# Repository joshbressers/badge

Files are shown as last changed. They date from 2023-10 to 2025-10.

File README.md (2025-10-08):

This code is no longer maintained, everything got too complicated. You should go to the new home of this project
https://github.com/OpenBadgeProject

# Open Badge Project



This is the Open Badge Project. The idea behind this is to have a very low cost, low power electronic badge. These could be built just for fun, or if you're throwing a conference, feel free to use the PCB as the badge, maybe build some, maybe let the folks at the conference build them.

Electronic badges have gotten pretty hip, but they seem to suffer from two primary problems.
1) They are very expensive
1) They need a lot of batteries

The goal of the Open Badge Project was to build a badge that costs $5 or less and can run for a day or more on one 2032 battery.

The badge as it stands right now will only cost $5 if you build A LOT (1000 or more). The cost is closer to $6 or $7 for smaller batches at the moment, but that's still pretty reasonable.

### Types
There are two versions of the badge. One is a through hole badge that's very easy to solder. It was designed with human fabricators in mind. The kicad files in the main branch are for the through hole model.

There is also a surface mount version in the [surface-mount](https://github.com/joshbressers/badge/tree/surface-mount) branch. This version of the badge can be sent off to a fabricator to be mass produced.

Both badge versions use the same code.

## How does it work?
The badge itself runs on a microprocessor called an ATTINY85. It has 8K of program space, 512 bytes (yes, bytes) of memory. That microprocessor then drives 3 shift registers. One for the button input, and two for the display output. Shift registers shouldn't be used to drive LEDs, but it works, and doing it this way keeps the cost down.

The PCB can be shipped off to one of the countless PCB manufacturers that exist. There is room on the front for a logo. There is also plenty of room on the back for graphics. Instructions for swapping in your own logo can be found below.

The PCB was designed using KiCad, version 7.0 to be precise. Your mileage may very if you try to use other versions.

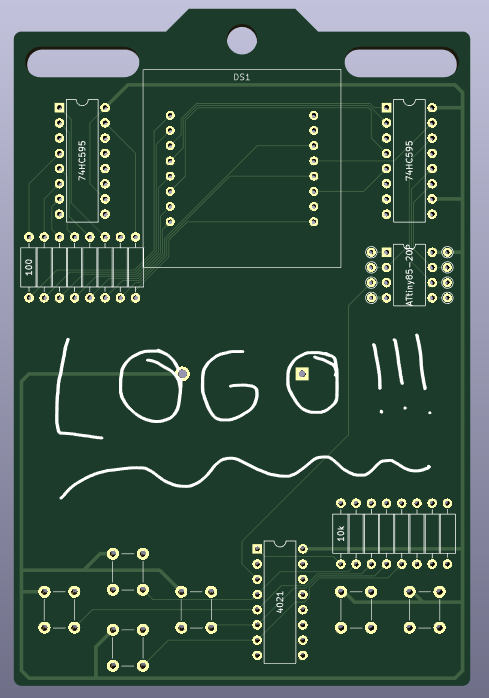
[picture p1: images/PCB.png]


## Parts List
You can generate a bill of materials from KiCad, but for the sake of simplicity here is a list of all the parts.

- 1 [ATTINY85](https://www.digikey.com/en/products/detail/microchip-technology/ATTINY85-20PU/735469)
- 1 PCB (you have to get this made, you can't buy them)
- 2 [CD74HC595E](https://www.digikey.com/en/products/detail/texas-instruments/CD74HC595E/1507396) shift registers
- 1 [CD4021BE](https://www.digikey.com/en/products/detail/texas-instruments/CD4021BE/67261) shift register
- 1 [2032 battery holder](https://www.digikey.com/en/products/detail/adam-tech/BH-25C-1/13537703)
- 8 [100 Ohm resistors](https://www.digikey.com/en/products/detail/stackpole-electronics-inc/CF14JT100R/1741261)
- 8 [100K Ohm resistors](https://www.digikey.com/en/products/detail/stackpole-electronics-inc/CF14JT10K0/1741265)
- 6 [Buttons](https://www.amazon.com/gp/product/B07VSNN9S2/ref=ppx_yo_dt_b_asin_title_o00_s00?ie=UTF8&th=1)
- 1 [8x8 LED Display](https://www.aliexpress.us/item/3256805713726832.html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)

There may be better places to purchase these things than these links. Please submit a PR if you find something better.

## How to change the logo
KiCad has a tool called "Image Converter". This application lets you turn an image into a footprint that can be added to the PCB layout.

When you run the tool, there is a button on the left called "Load Source Image". If you have a black and white image to start with that's the best. You can use any image but things get weird.

Once you load an image you will need to watch the size. The "Output Size" field is what matters here. It will take a few tries to get it right. There's about 3 inches by 1.7 inches of space to work with on the front.

Use the "Front Solder Mask" layer. Make sure you use Footprint for the output layer.

Click Export to file. Save the file in the badge-footprints.pretty directory.

Now open the "PCB Editor" application. Make sure the "F. Silkscreen" layer is selected on the right.

You will have to click on and delete the existing logo. Now from the menu Place -> Add Footprint

If you search for "badge" in the text box you should see your logo show up in the list. Double click it, then place it where it fits. If the logo isn't sized right, go back to the Image Converter and try again.

## How to order PCBs
If you want to have PCBs made, you need to export the Gerber files from the PCB Editor. The Gerber files are what you send the PCB manufacturer.

Run the PCB Editor, then File -> Fabrication Outputs -> Gerbers

Create a new directory to hold the files (there will be more than one). For example let's call it badge_gerber. Leave the default settings alone, it should do the right thing.

Then click Plot. Then click "Generate Drill Files" and "Generate Drill File" on the window that pops up. Your directory now has the files need to create the PCB in it.

The PCB manufacturer will want that directory turned into a zip file and uploaded. You're on your own to figure that part out.

## How to program the chip

In order to program the ATTINY85 you will need a programmer. There is a lovely page that explains how to use an arduino as your [programmer](https://www.instructables.com/How-to-Program-an-Attiny85-From-an-Arduino-Uno/)

The reset pin on this chip is special. We are purposely not using that pin (so we really only have 5 IO pins now) because if you use the reset pin, you now require a high voltage programmer. Since we want people to program this thing using only an arduino, we'll keep the reset pin free.

## How to develop for the badge
See [DEVELOPING.md](DEVELOPING.md)

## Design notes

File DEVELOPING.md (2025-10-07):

## Developing for the badge

The code that makes everything go is in the badge directory. This is meant to be used with the Arduino development environment.

If you haven't done so, you should follow the instructions in the README about programming the ATTINY85 with an Arduino. Even if you're not using an Arduino to program the chip, there are instructions there for getting the Arduino environment configured. Both 1.x and 2.x Arduino IDEs work.

The files are hopefully well commented so what's happening in them is clear. Keep in mind that most decisions made were to make things as simple and efficient as possible. There's very little memory and not much program space. Sometimes using more memory was used to make things easier for humans. Like using floats in the pong game. Integers take up less room and would be faster, but would be harder to understand the code.

The best way to figure this thing out is to play around with the code. Look at the examples and ask questions (file all the issues you want).

## File layout

There are a few critical files for the operation of the badge.

### badge.ino
The [badge.ino](badge/badge.ino) file is where the setup and main loop exist. If you've ever programmed for an Arduino before, this should be familiar to you. If you haven't, you may want to look at some Arduino programming tutorials first.

### constants.h
[constants.h](badge/constants.h) is where all the constants are means to be held. The stuff you can modify is at the top.

These are the things used across the various functions that make the badge work. When possible you should use #define instead of declaring variables. There's not much memory, variables are expensive. This file should be very well commented. If something isn't clear please file an issue.

### font.h
[font.h](badge/font.h) is where the font to scroll a message across the screen exists. It's an 8x5 font that takes up 5 bytes per character.

For example the letter A is:
```
0x7C, 0x12, 0x11, 0x12, 0x7C,
```
If we turn that into binary, we can see what the letter looks like

```
01111100
00010010
00010001
00010010
01111100
```
or if we rotate it and use some friendlier characters
```
..#..
.#.#.
#...#
#...#
#####
#...#
#...#
.....
```
Every byte is a column in the font

The font characters are in ASCII order, so we can address them by converting a byte character into a uint8_t and subtracting 0x20.

If you want to add new characters, do it at the end of the array.

### shift_registers.ino

The [shift_registers.ino](badge/shift_registers.ino) file is where we read/write to the shift registers. This is how we update the screen and read the buttons. This is the file that actually makes all the hardware work.

The various millis() functions of the Arduino use up memory. Rather than try to use those, we have a variable called currentTick in this file that ticks up one every loop of the application and reads/writes the shift registers. Every subroutine has to call the runTick() function while it loops.

We could consider using a timer interrupt for this someday. How to handle a partially updated frameBuffer is why this hasn't happened yet (it's possible things update fast enough it won't matter). NOTE: I tried doing this in a [branch](https://github.com/joshbressers/badge/tree/interrupt), it's not very good.

The shiftRegisters() function is mostly unexciting but also drives everything. It pulses the latches and clocks then reads/writes the data. Whatever is in the frameBuffer variable gets written to the screen. Whatever buttons are pressed get written to CUR_BUTTON.

### message.ino
[message.ino](badge/message.ino) is the file that scrolls text on the screen. It has a lot of comments, go read them.

Most of the text that is displayed is stored in PROGMEM. This is a special variable in the Arduino universe that places the text in the 8K of program space instead of our 512 bytes of RAM. As such, PROGMEM needs to be read differently than a normal variable.

We have a variable in the code called a "progmemMessage". It's possible to print a string from memory, or a string from PROGMEM space. You just have to call either setMessage for PROGMEM strings or setMemMessage for memory strings.

This is all confusing, the printScore function is probably worth looking at. There are probably ways to make this simpler with some C++ magic.

### menu.ino
[menu.ino](badge/menu.ino) is where we drive the main menu from. If you want to add a program, you have to register it here. It's pretty easy to understand, go look at it.

### tests.ino
[tests.ino](badge/tests.ino) contain two tests. One to test the buttons and one to show a pattern on the screen. They don't take up very much space and help with debugging.

### move_dot.ino
[simple_games.ino](badge/simple_games.ino) is where the games are currently held. There's no reason to add games here, it was a way to avoid adding too many files.

### blocks.ino
[blocks.ino](badge/blocks.ino) is a tetris like clone. It has some bugs and isn't amazing. Patches welcome

### rain.ino
[rain.ino](badge/rain.ino) is a little tool that draws rain waves on the screen. It's interesting because of the circle drawing function

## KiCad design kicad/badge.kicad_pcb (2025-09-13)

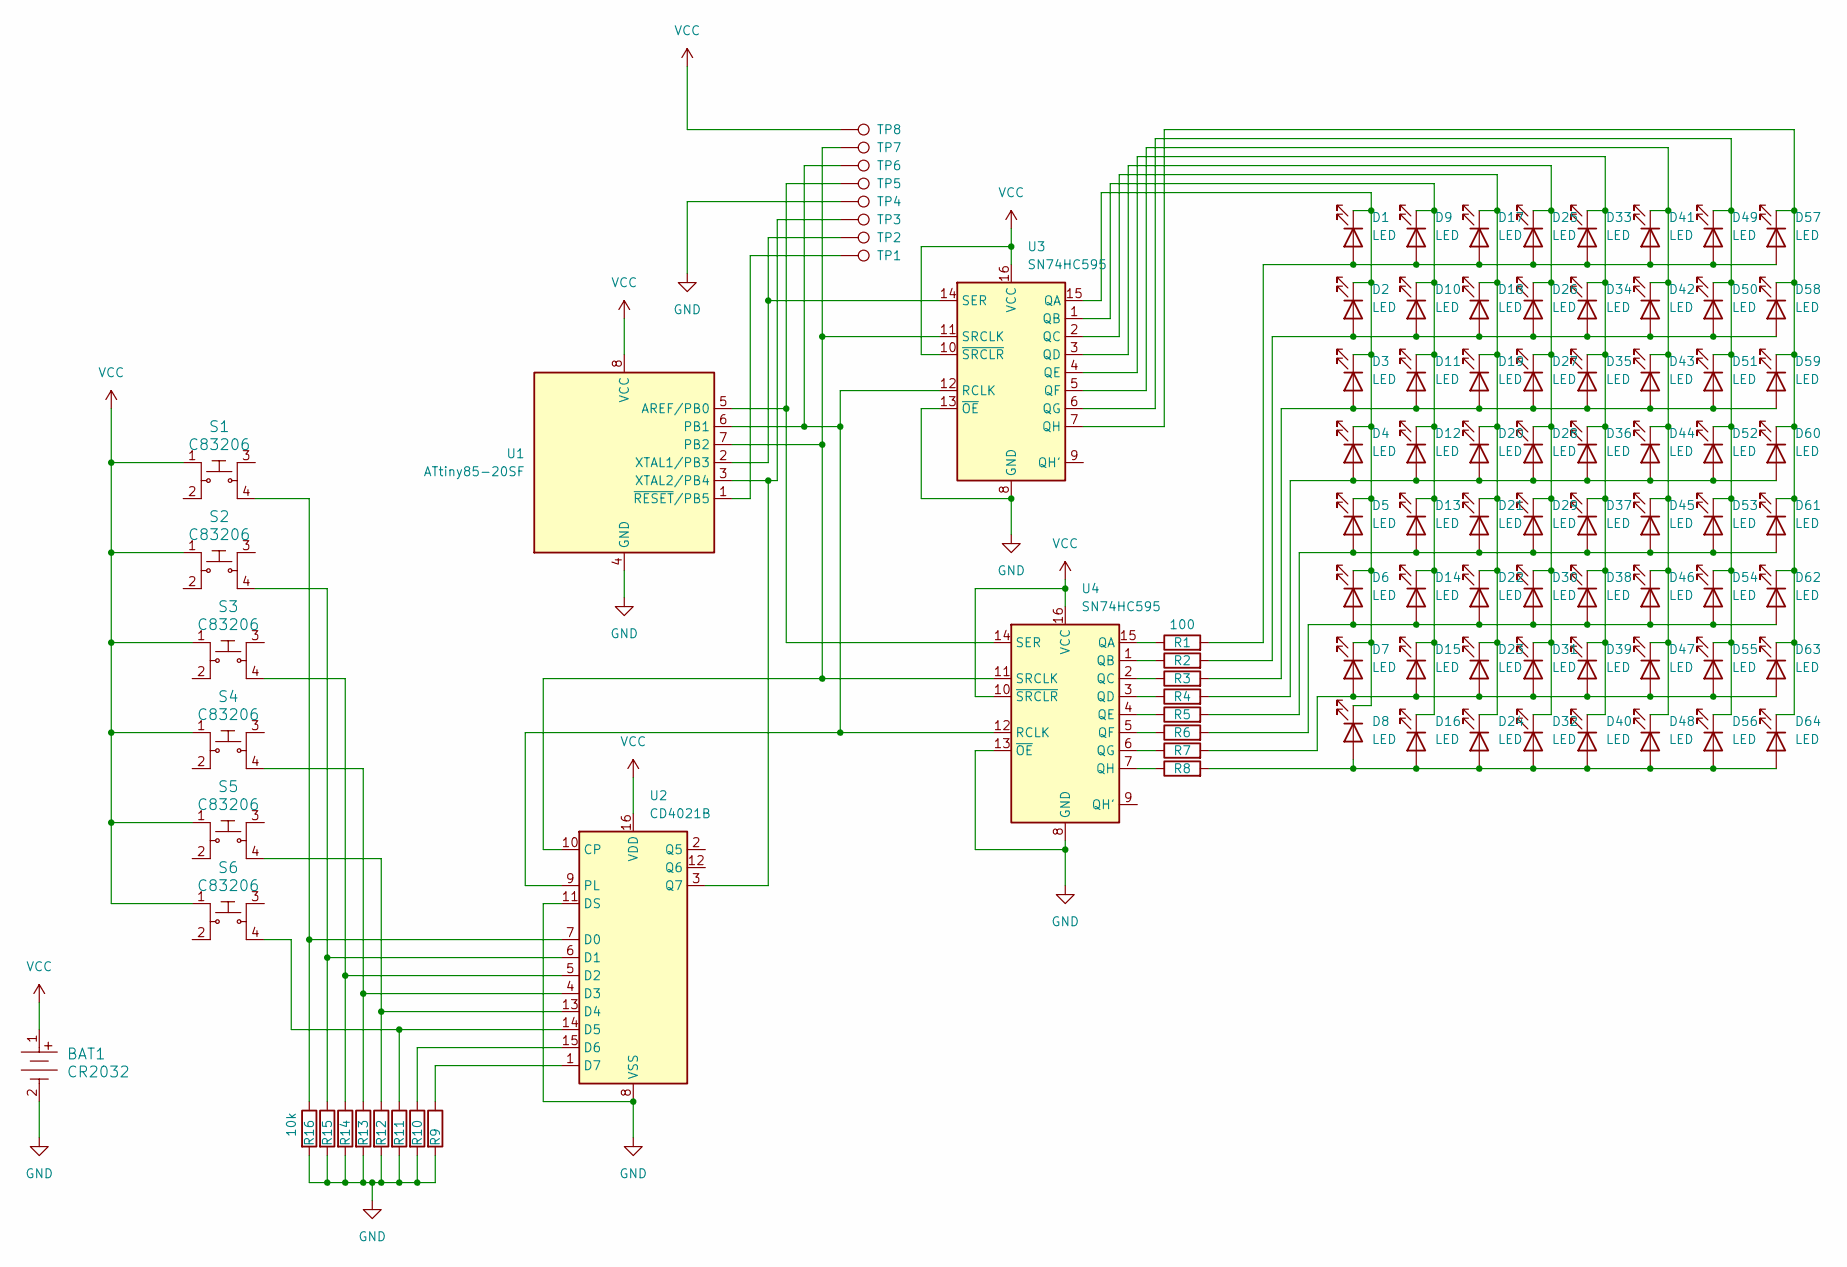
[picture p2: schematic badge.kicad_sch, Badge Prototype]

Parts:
BAT1: CR2032; BatteryHolder_MPD_BC2003_1x2032; MPN BS-7; JLCPCB Part # C70373
D1, D2, D3, D4, D5, D6, D7, D8, D9, D10, D11, D12, D13, D14, D15, D16, D17, D18, D19, D20, D21, D22, D23, D24, D25, D26, D27, D28, D29, D30, D31, D32, D33, D34, D35, D36, D37, D38, D39, D40, D41, D42, D43, D44, D45, D46, D47, D48, D49, D50, D51, D52, D53, D54, D55, D56, D57, D58, D59, D60, D61, D62, D63, D64: LED; LED_1206_3216Metric_Pad1.42x1.75mm_HandSolder
R1, R2, R3, R4, R5, R6, R7, R8: 100; R_0805
R9, R10, R11, R12, R13, R14, R15, R16: 10k; R_0805
S1: C83206; SW_MEC_5GSH9
S2, S3, S4, S5, S6: C83206; MPN TL3315NF160Q; Digi-Key_PN EG4621CT-ND
TP1, TP2, TP3, TP4, TP5, TP6, TP7, TP8: TestPoint; TestPoint_THTPad_D1.5mm_Drill0.7mm
U1: ATtiny85-20SF; SOIC-8_5.3x5.3mm_P1.27mm; JLCPCB Part # C615549
U2: CD4021B; SOIC-16_L9.9-W3.9-P1.27-LS6.0-BL; JLCPCB Part # C6729
U3, U4: SN74HC595; SOIC-16_L9.9-W3.9-P1.27-LS6.0-BL; JLCPCB Part # C5947

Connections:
GND: BAT1.2, R9.2, R10.2, R11.2, R12.2, R13.2, R14.2, R15.2, R16.2, TP4.1, U1.4 (GND), U2.8 (VSS), U2.11 (DS), U3.8 (GND), U3.13 (~OE), U4.8 (GND), U4.13 (~OE)
unnamed: D1.2 (A), D9.2 (A), D17.2 (A), D25.2 (A), D33.2 (A), D41.2 (A), D49.2 (A), D57.2 (A), R1.2
unnamed: D1.1 (K), D2.1 (K), D3.1 (K), D4.1 (K), D5.1 (K), D6.1 (K), D7.1 (K), D8.1 (K), U3.15 (QA)
unnamed: D2.2 (A), D10.2 (A), D18.2 (A), D26.2 (A), D34.2 (A), D42.2 (A), D50.2 (A), D58.2 (A), R2.2
unnamed: D9.1 (K), D10.1 (K), D11.1 (K), D12.1 (K), D13.1 (K), D14.1 (K), D15.1 (K), D16.1 (K), U3.1 (QB)
unnamed: D3.2 (A), D11.2 (A), D19.2 (A), D27.2 (A), D35.2 (A), D43.2 (A), D51.2 (A), D59.2 (A), R3.2
unnamed: D4.2 (A), D12.2 (A), D20.2 (A), D28.2 (A), D36.2 (A), D44.2 (A), D52.2 (A), D60.2 (A), R4.2
unnamed: D5.2 (A), D13.2 (A), D21.2 (A), D29.2 (A), D37.2 (A), D45.2 (A), D53.2 (A), D61.2 (A), R5.2
unnamed: D6.2 (A), D14.2 (A), D22.2 (A), D30.2 (A), D38.2 (A), D46.2 (A), D54.2 (A), D62.2 (A), R6.2
unnamed: D7.2 (A), D15.2 (A), D23.2 (A), D31.2 (A), D39.2 (A), D47.2 (A), D55.2 (A), D63.2 (A), R7.2
unnamed: D8.2 (A), D16.2 (A), D24.2 (A), D32.2 (A), D40.2 (A), D48.2 (A), D56.2 (A), D64.2 (A), R8.2
unnamed: D17.1 (K), D18.1 (K), D19.1 (K), D20.1 (K), D21.1 (K), D22.1 (K), D23.1 (K), D24.1 (K), U3.2 (QC)
unnamed: D25.1 (K), D26.1 (K), D27.1 (K), D28.1 (K), D29.1 (K), D30.1 (K), D31.1 (K), D32.1 (K), U3.3 (QD)
unnamed: D33.1 (K), D34.1 (K), D35.1 (K), D36.1 (K), D37.1 (K), D38.1 (K), D39.1 (K), D40.1 (K), U3.4 (QE)
unnamed: D41.1 (K), D42.1 (K), D43.1 (K), D44.1 (K), D45.1 (K), D46.1 (K), D47.1 (K), D48.1 (K), U3.5 (QF)
unnamed: D49.1 (K), D50.1 (K), D51.1 (K), D52.1 (K), D53.1 (K), D54.1 (K), D55.1 (K), D56.1 (K), U3.6 (QG)
unnamed: D57.1 (K), D58.1 (K), D59.1 (K), D60.1 (K), D61.1 (K), D62.1 (K), D63.1 (K), D64.1 (K), U3.7 (QH)
unnamed: TP5.1, U1.5 (AREF/PB0), U4.14 (SER)
unnamed: TP6.1, U1.6 (PB1), U2.9 (PL), U3.12 (RCLK), U4.12 (RCLK)
unnamed: TP7.1, U1.7 (PB2), U2.10 (CP), U3.11 (SRCLK), U4.11 (SRCLK)
unnamed: TP2.1, U1.2 (XTAL1/PB3), U3.14 (SER)
unnamed: TP3.1, U1.3 (XTAL2/PB4), U2.3 (Q7)
unnamed: TP1.1, U1.1 (~RESET/PB5)
unnamed: R16.1, S1.4, U2.7 (D0)
unnamed: R15.1, S2.4, U2.6 (D1)
unnamed: R14.1, S3.4, U2.5 (D2)
unnamed: R13.1, S4.4, U2.4 (D3)
unnamed: R12.1, S5.4, U2.13 (D4)
unnamed: R11.1, S6.4, U2.14 (D5)
unnamed: R10.1, U2.15 (D6)
unnamed: R9.1, U2.1 (D7)
unnamed: R1.1, U4.15 (QA)
unnamed: R2.1, U4.1 (QB)
unnamed: R3.1, U4.2 (QC)
unnamed: R4.1, U4.3 (QD)
unnamed: R5.1, U4.4 (QE)
unnamed: R6.1, U4.5 (QF)
unnamed: R7.1, U4.6 (QG)
unnamed: R8.1, U4.7 (QH)
VCC: BAT1.1, S1.1, S2.1, S3.1, S4.1, S5.1, S6.1, TP8.1, U1.8 (VCC), U2.16 (VDD), U3.10 (~SRCLR), U3.16 (VCC), U4.10 (~SRCLR), U4.16 (VCC)

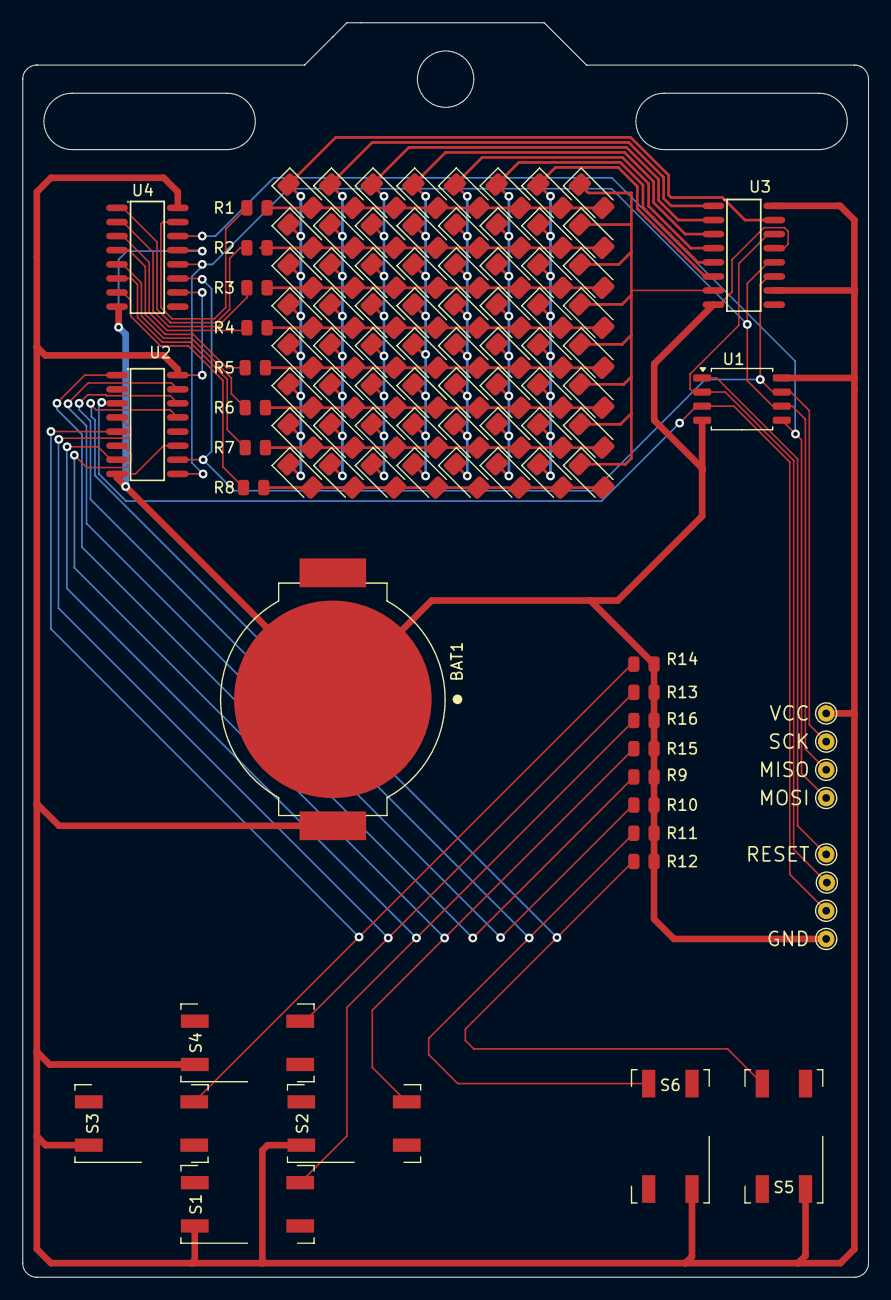
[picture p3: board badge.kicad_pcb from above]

Board: 2 copper layers, 76.2 x 113.0 mm, 99 parts (0 on the bottom side), 40 nets.

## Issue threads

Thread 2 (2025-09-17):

Use the V type of the ATTINY

joshbressers, 2025-09-17:
https://www.reddit.com/r/arduino/comments/1lqrq4/what_are_the_realworld_differences_between_they/

It seems that the non-V version can operate up to 20MHz and has a minimum voltage of 2.7V (at <10MHz, you still need 4.5V for 20MHz).

The V version can only operate up to 10MHz, but the minimum voltage is 1.8V (at <4MHz, 2.7V is needed for 10MHz).

You can still run the non-V version at, say, 4MHz, but you will need at least a 2.7V supply.

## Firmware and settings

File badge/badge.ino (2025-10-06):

#include "constants.h"

uint8_t code_count = 0;

const char secretCode[] = {
  BTN_UP,
  BTN_UP,
  BTN_DOWN,
  BTN_DOWN,
  BTN_LEFT,
  BTN_RIGHT,
  BTN_LEFT,
  BTN_RIGHT,
  BTN_B,
  BTN_A
};

void setup() {
//set pins to output so you can control the shift register

// We will talk straight to the input/output register
// By not using the arduino digitalWrite functionality
// We save 500 bytes and it's substantially faster
DDRB |= (1 << latchPin);			// output
DDRB |= (1 << clockPin);
DDRB |= (1 << dataPin1);
DDRB |= (1 << dataPin2);
DDRB &= ~(1 << buttonPin); // input

setMessage(defaultMessage, true);
}

void loop() {
  runTick();
  showMessage();

  // If we see a new keypress, load the menu
  // The bitwise XOR is here because we don't want a
  // held down button to triger the menu, which happens when you
  // select back from the menu (or anything else that could have an exit)
#ifdef SecretCode
  if (CUR_BUTTON && (CUR_BUTTON ^ OLD_BUTTON)) {
    if (secretCode[code_count] == CUR_BUTTON) {
      code_count++;
      if (code_count == sizeof(secretCode)) {
        code_count = 0;
        printMessage(codez, true);
        setMessage(defaultMessage, true);
      }
    } else {
      code_count = 0;
      showMenu(mainMenu, mainMenuLen, HOME_TIMEOUT);
      setMessage(defaultMessage, true);
    }
  }
#endif
#ifndef SecretCode
  if (CUR_BUTTON && (CUR_BUTTON ^ OLD_BUTTON)) {
      showMenu(mainMenu, mainMenuLen, HOME_TIMEOUT);
      setMessage(defaultMessage, true);
  }
#endif
}

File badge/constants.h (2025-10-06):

#ifndef CONSTANTS_H
#define CONSTANTS_H

#include <avr/io.h>
#include "font.h"

// Things you might want to change are all located here

// Games to enable
//#define DotGame
//#define PongGame
//#define SpaceGame
//#define RainGame
//#define BlockGame
//#define CustomMessage
//#define EnableTests

// Comment this out if you don't want a secret code
//#define SecretCode

// This is the default message that scrolls across the badge by default
const char defaultMessage[] PROGMEM = "Default Badge Message ";
const char codez[] PROGMEM = "sekrit codez!!!  ";

// The speed at which the message scrolls. Bigger numbers scroll slower
#define messageDelay 30

// How many ticks should we wait until we return to home screen
// Bigger numbers wait longer
#define HOME_TIMEOUT 3000


// Below here are things you probably shouldn't change


// Constants

// Hardware related constants

// Shift register pins
#define latchPin PB1
#define clockPin PB2

////Pin connected to DS of 74HC595
#define dataPin1 PB0 // SR 1
#define dataPin2 PB3 // SR 2
#define buttonPin PB4 // Button Input

// Frame buffer variables
byte frameBuffer[] = {0,0,0,0,0,0,0,0};

// Message display constants
const char* message;
unsigned int messageLen = 0;

const char scoreMessage[] PROGMEM = "Score ";


// Constants used when writing the message to the framebuffer
unsigned int messageCount = 0;
unsigned int lastButton = 0;

// Tick constants
// The millis() on this chip isn't very reliable, so let's just count up a tick
// on every loop
unsigned int currentTick = 0;

// State booleans
bool donePrinting = false;

// TICK can be used for delay loops. Pass it in a value to return true
// after a certain amount of time has passed.
#define TICK(the_tick) (!(currentTick % the_tick))

// This has to be run by every function. A timeout of zero can be passed in
// to not ever timeout. If no timeout is used it's up to the function
// to return
#define LOOP(loop_define_timeout) {\
  runTick();\
  if (loop_define_timeout && (lastButton > loop_define_timeout)) {\
    return;\
  }\
}

// The Arduino random() code uses up 500 bytes, we'll use our own
#define RANDOM(rand_ceiling) (random32() % rand_ceiling)

// Button Constants
#define BTN_A 0x10
#define BTN_B 0x20
#define BTN_LEFT 0x04
#define BTN_RIGHT 0x02
#define BTN_UP 0x08
#define BTN_DOWN 0x01

uint8_t CUR_BUTTON = 0x00;
uint8_t OLD_BUTTON = 0x00;

// Button functionality

// This will return true if a button is pressed for the first time
// A held down button will return false
#define NEW_BUTTON(the_btn) ((CUR_BUTTON & the_btn) && !(OLD_BUTTON & the_btn))

// Return true if the button is pressed
#define PUSH_BUTTON(the_btn) (CUR_BUTTON & the_btn)

// Define our functions here
void setMessage(unsigned char *newMessage, bool progMem);
void printMessage(unsigned char *newMessage, bool progmemMessage);
void printScore(unsigned int score);
void shiftRegisters();
void showMessage();
void clearFrameBuffer();
void moveDot();
void showMenu();
void screenTest();
void buttonTest();
void runTick();
void pongGame();
void spaceGame();
void showRain();
void customMessage();
uint32_t random32();
void teh_code();
void badgeBlock();
void getString(unsigned char *theString);



// Main Menu things

// Menu static text
const char menu0[] PROGMEM = "Menu ";
const char menu1[] PROGMEM = "Test Buttons ";
const char menu2[] PROGMEM = "Dot ";
const char menu3[] PROGMEM = "Test Screen ";
const char menu4[] PROGMEM = "Pong ";
const char menu5[] PROGMEM = "Space ";
const char menu6[] PROGMEM = "Rain ";
const char menu7[] PROGMEM = "Custom Message ";
const char menu8[] PROGMEM = "Badgetris ";

typedef struct badgeStruct {
  const char *programName;
  void (*badgeFunction)(void);
};

badgeStruct mainMenu[] = {
  {
    menu0,
    NULL
  },
#ifdef CustomMessage
  {
    menu7,
    (*customMessage)
  },
#endif
#ifdef BlockGame
  {
    menu8,
    (*badgeBlock)
  },
#endif
#ifdef RainGame
  {
    menu6,
    (*showRain)
  },
#endif
#ifdef DotGame
  {
    menu2,
    (*moveDot)
  },
#endif
#ifdef PongGame
  {
    menu4,
    (*pongGame)
  },
#endif
#ifdef SpaceGame
  {
    menu5,
    (*spaceGame)
  },
#endif
#ifdef EnableTests
  {
    menu1,
    (*buttonTest)
  },

  {
    menu3,
    (*screenTest)
  }
#endif

};

uint8_t mainMenuLen = sizeof(mainMenu) / sizeof(mainMenu[0]);
void showMenu(badgeStruct *thePrograms, uint8_t menuMax, uint16_t menuTimeout);

#endif

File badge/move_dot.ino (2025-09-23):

#include "constants.h"

void moveDot() {
  uint8_t x = 4 * 32;
  uint8_t y = 4 * 32;
  int8_t x_vel = 0;
  int8_t y_vel = 0;

  while(true) {
    LOOP(0);
    clearFrameBuffer();
  
    if (NEW_BUTTON(BTN_RIGHT)) x_vel++;
    if (NEW_BUTTON(BTN_DOWN)) y_vel++;
    if (NEW_BUTTON(BTN_UP)) y_vel--;
    if (NEW_BUTTON(BTN_LEFT)) x_vel--;

    if (NEW_BUTTON(BTN_A)) {
      x = 4 * 32;
      y = 4 * 32;
      x_vel = 0;
      y_vel = 0;
    } else if (NEW_BUTTON(BTN_B)) {
      return;
    }

    x = x + x_vel;
    y = y + y_vel;

    //frameBuffer[x/32] = 1 << (y/32);
    setFrameBuffer(x/32, y/32);
  }
}

void drawCircle(int xc, int yc, int x, int y){
    setFrameBuffer(xc+x, yc+y);
    setFrameBuffer(xc-x, yc+y);
    setFrameBuffer(xc+x, yc-y);
    setFrameBuffer(xc-x, yc-y);
    setFrameBuffer(xc+y, yc+x);
    setFrameBuffer(xc-y, yc+x);
    setFrameBuffer(xc+y, yc-x);
    setFrameBuffer(xc-y, yc-x);
}

void circleBres(int xc, int yc, int r){
    int x = 0, y = r;
    int d = 3 - 2 * r;
    drawCircle(xc, yc, x, y);
    while (y >= x){
      
        // check for decision parameter
        // and correspondingly 
        // update d, y
        if (d > 0) {
            y--; 
            d = d + 4 * (x - y) + 10;
        }
        else
            d = d + 4 * x + 6;

        // Increment x after updating decision parameter
        x++;
        
        // Draw the circle using the new coordinates
        drawCircle(xc, yc, x, y);
    }
}

void showRain() {
  uint8_t x = 4;
  uint8_t y = 3;
  uint8_t loopCount = 0;
  uint8_t rainSpeed = 100;

  while(true) {

    clearFrameBuffer();

    if (loopCount == 0)
      setFrameBuffer(x, y);
    else
      circleBres(x, y, loopCount);

    for (int i = 0; i < rainSpeed; i++) {
      LOOP(0);
      if (NEW_BUTTON(BTN_DOWN)) rainSpeed++;
      if (NEW_BUTTON(BTN_UP)) rainSpeed--;
      if (NEW_BUTTON(BTN_B)) return;
    }
    loopCount++;
    if (loopCount > 9) {
      loopCount = 0;
      x = RANDOM(8);
      y = RANDOM(8);
    }
  }
}

void pongGame() {
  float ball_x = 3;
  float ball_y = 2;
  unsigned int score = 0;
  float ball_x_vel = 0.012;
  float ball_y_vel = 0.01;

  float paddle_x = 0;

  if (RANDOM(2)) ball_x_vel = -0.012;
  if (RANDOM(2)) ball_y_vel = -0.01;

  while(true) {
    LOOP(0);
    clearFrameBuffer();
  
    if (PUSH_BUTTON(BTN_RIGHT) && paddle_x < 5) {
      paddle_x = paddle_x + 0.05;
    }
    if (PUSH_BUTTON(BTN_LEFT) && paddle_x > 0) {
      paddle_x = paddle_x - 0.05;
    }

    if (NEW_BUTTON(BTN_B)) {
      return;
    }

    ball_x = ball_x + ball_x_vel;
    if ((ball_x >= 7) || (ball_x < 1)) ball_x_vel = ball_x_vel * -1;
    ball_y = ball_y + ball_y_vel;
    if ((ball_y >= 7) || (ball_y < 1)) ball_y_vel = ball_y_vel * -1;

    // We're at the paddle, did we hit it?
    if (ball_y >= 7) {
      if ((ball_x >= paddle_x) && (ball_x <= paddle_x + 3 )) {
        score++;
        if (!RANDOM(3)) ball_x_vel = ball_x_vel * -1;

      } else {
        printScore(score);
        return;
      }
    }

    // Draw the ball
    setFrameBuffer((int)ball_x, (int)ball_y);

    // Draw the paddle
    for (int i = 0; i < 3; i++) {
      setFrameBuffer((int)paddle_x+i, 7);
    }
  }
}

void spaceGame() {
  unsigned int score = 0;

  // The ship will be offset by one
  // If we try to use -1 as the leftmost range
  // We end up with the problme of >-1 to <1 is zero,
  // Which is too wide of a range. Think of zero on
  // ship as the middle, not the side
  float ship_x = 4;
  float bullet_x = 0;
  float bullet_y = 0;

  float alien_x = 0;
  float alien_y = -1;

  while(true) {
    LOOP(0);
    clearFrameBuffer();

    if (alien_y < 0) {
      // No alien, let's add one
      // Also, why are aliens always the bad guys?
      // Very Ender's Game

      alien_y = 0;
      alien_x = RANDOM(7);
      
    } else if (alien_y >= 7) {
      printScore(score);
      return;
    }else {
      setFrameBuffer((int)alien_x, (int)alien_y);
      setFrameBuffer((int)alien_x + 1, (int)alien_y);
      alien_y = alien_y + 0.005 + score * 0.001;
    }

    
    if (PUSH_BUTTON(BTN_RIGHT) && ship_x < 7) {
      ship_x = ship_x + 0.04;
    }
    if (PUSH_BUTTON(BTN_LEFT) && ship_x > 0) {
      ship_x = ship_x - 0.04;
    }
    if (NEW_BUTTON(BTN_A) && bullet_y <= 0) {
      bullet_x = ship_x;
      bullet_y = 6;
    }

    if (bullet_y > 0) {
      setFrameBuffer((int)bullet_x, (int)bullet_y);

      if ((int(bullet_y) == (int)alien_y) && ((int)bullet_x >= (int)alien_x && (int)bullet_x <= ((int)alien_x + 1))) {
        alien_y = -10;
        alien_x = -10;
        bullet_y = -10;
        score++;
      }
      
      bullet_y = bullet_y - 0.05;
    }

    // Draw the ship
    if (ship_x > 0)
      //frameBuffer[(int)ship_x - 1] = frameBuffer[(int)ship_x - 1] | 0x80;
      setFrameBuffer((int)ship_x - 1, 7);
    //frameBuffer[(int)ship_x] = frameBuffer[(int)ship_x] | 0xC0;
    setFrameBuffer((int)ship_x, 6);
    setFrameBuffer((int)ship_x, 7);
    if (ship_x <= 6)
      //frameBuffer[(int)ship_x + 1] = frameBuffer[(int)ship_x + 1] | 0x80;
      setFrameBuffer((int)ship_x + 1, 7);
  }
}

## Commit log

2023-08-29 Move things around to make the Arduino IDE happy
2023-09-09 Rework the control flow
    [badge.ino, constants.h, menu.ino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]
2023-09-09 Fix the button reading
    [constants.h, menu.ino, move_dot.ino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]
2023-09-10 Fix the strings and fonts
    [constants.h, menu.ino]
2023-09-11 Fix the screen test
    [tests.ino]
2023-09-15 Add the kicad files
    [badge.kicad_pcb, badge.kicad_sch]
2023-09-16 Update badge with latest version
    [badge.kicad_pcb, badge.kicad_sch]
2023-09-22 Update badge PCB
    [badge.kicad_pcb, badge.kicad_sch]
2023-09-23 Use correct buttons
2023-09-28 Add changes to badge to match reality
    [badge.kicad_pcb]
2023-09-28 Fix the revision numbers
    [badge.kicad_pcb, badge.kicad_sch]
2023-10-09 Add a note about interrupts
2023-10-09 Add PCB image
2025-06-20 Add surface mount parts
    [badge.kicad_pcb, badge.kicad_sch]
2025-09-13 Update surface mount badge
    [badge.kicad_pcb, badge.kicad_sch]
2025-09-13 Update badge
    [badge.kicad_pcb]
2025-09-23 Fix the space game
    [simple_games.ino]
2025-09-28 Fix the test for end of string
    [message.ino]
